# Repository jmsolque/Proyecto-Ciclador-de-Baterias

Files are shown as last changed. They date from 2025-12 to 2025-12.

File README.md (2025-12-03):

# Proyecto-Ciclador-de-Baterias
Este repositorio contiene los archivos correspondientes a un ciclador de módulos de baterías.

## Documentación

### Componentes Utilizados
<div align="center">

| Componente | Cantidad | Modelo | Utilización |
|:---:|:---:|:---:|:---:|
| Fuente de tensión | 1 | x | Alimentar algunos de los componentes utilizados. |
| Conversor DC/DC | 1 | TBA 1E | Tener tanto tensión positiva como negativa. |
| Varistor | 1 | x | Circuito de protección. |
| Resistencia 100 KΩ | 1 | x | Circuito de protección. |
| Diodo Zener | 1 | 1N4747 | Circuito de protección. |
| Transistor MOSFET | 1 | IRF9540N | Circuito de protección. |
| Transistor NPN | 2 | TIP120 | Uno para carga y otro para descarga. |
| Disipador Térmico | 2 | x | Disipar el calor de los transistores. |
| Inductor 10µH | 2 | x | Dos, para regular corriente de carga y descarga y poder utilizar el sistema de control. |
| Amplificador Operacional | 1 | LM353 | Controlar si funciona el circuito de carga o de descarga. |
| Sensores de Corriente | 2 | x | Para medir las corrientes de carga y descarga. |
| Delfino | 1 | C2000 | Controlador. |
| Medidor de Tensión | 1 | x | Incorporado en el C2000, para medir la tensión de la batería. |
| Convertidor Digital Analógico | 1 | x | Controlar si descarga o carga. |

</div>

### Ecuaciones utilizadas

La ecuación utilizada para el circuito de carga es:

$$
0 = -V_{carga} + L\frac{di_c}{dt} + V_{batería} 
$$

De donde se tiene que:

$$
V_{carga} = V_{cc} + V_{cp} 
$$

Con base en lo anterior, se considera que: 

$$ 
V_{cp} = V_{\text{batería}} 
$$

Esta igualdad se logra mediante un sistema de prealimentación que compensa la caída de tensión en los elementos intermedios y asegura que el valor aplicado en el punto de control coincida con el voltaje real de la batería.

Por lo cual se tiene que:

$$
\frac{di_c}{dt} = \frac{V_{cc}}{L}
$$

Y de esta forma la función de transferencia será:

$$
\frac{i_c(s)}{V_{cc}(s)} = \frac{1}{Ls}
$$

De forma similar se tendrá para el el circuito de descarga, para el cual lo de realizar los cálculos pertinentes se tendría que la función de transferencia sería.

$$
\frac{i_c(s)}{V_{dc}(s)} = -\frac{1}{Ls}
$$

Donde Vdc es la tensión de descarga.

## [PLECS](PLECS/)

En esta sección se encuentra el código utilizado para la implementación en PLECS y así poder utilizar un C2000, en esta misma también se muestran las simualciones.

## [PCB](PCB/)

En esta sección se encuentran los archivos utilizados para la creación de la PCB.

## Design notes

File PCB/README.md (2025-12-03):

# PCB

En esta sección se encuentran los archivos para la impresión de la PCB, junto con imágenes de referencia.

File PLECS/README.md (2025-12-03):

# PLECS

En esta sección se tiene la implementación en PLECS y a su vez las imágenes de las simulaciones obtenidas del mismo, como lo son su sistema de control y los circuitos de carga y descarga.

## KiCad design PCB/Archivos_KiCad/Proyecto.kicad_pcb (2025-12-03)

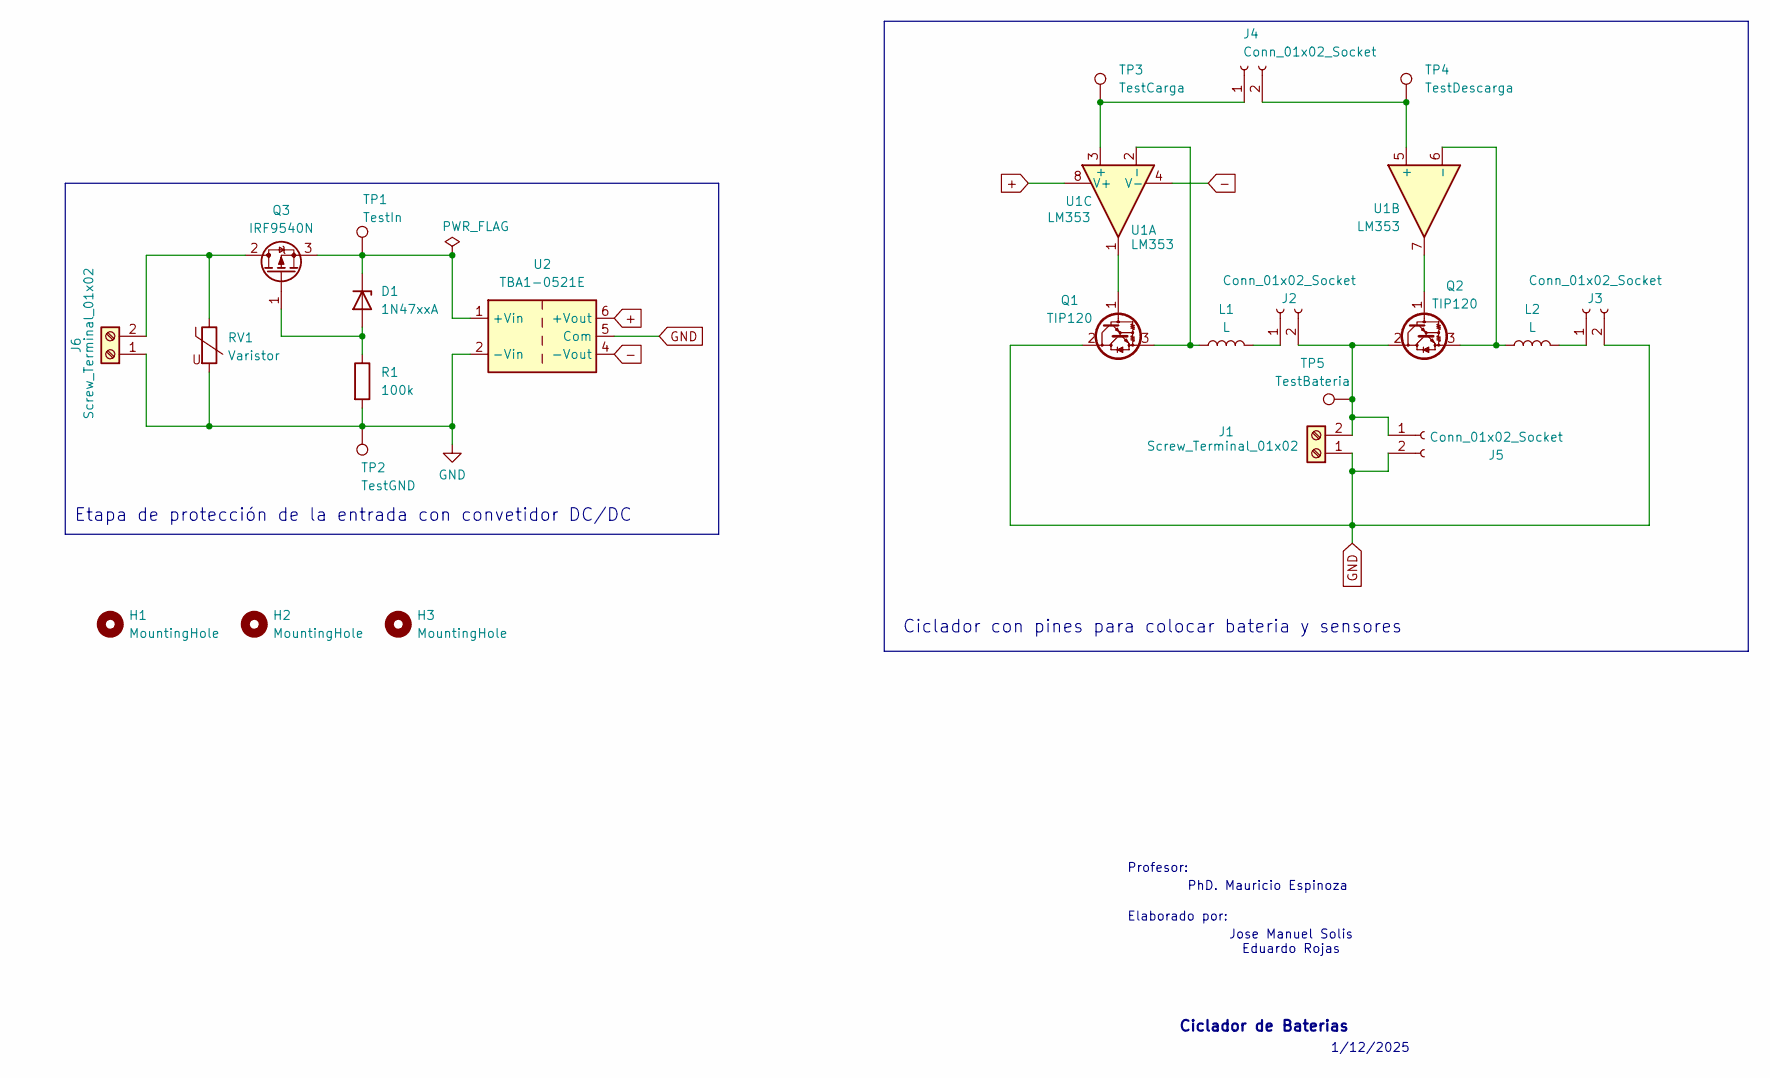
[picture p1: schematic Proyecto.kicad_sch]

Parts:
D1: 1N47xxA; D_DO-41_SOD81_P10.16mm_Horizontal
H1, H2, H3: MountingHole; MountingHole_2.2mm_M2
J1, J6: Screw_Terminal_01x02; TerminalBlock_Phoenix_MKDS-1,5-2_1x02_P5.00mm_Horizontal
J2, J3, J4, J5: Conn_01x02_Socket; PinSocket_1x02_P2.00mm_Vertical
L1, L2: L; L_Axial_L5.3mm_D2.2mm_P7.62mm_Horizontal_Vishay_IM-1
Q1, Q2: TIP120; TO-220-3_Vertical
Q3: IRF9540N; TO-220-3_Vertical
R1: 100k; R_Axial_DIN0207_L6.3mm_D2.5mm_P7.62mm_Horizontal
RV1: Varistor; RV_Disc_D7mm_W4mm_P5mm
TP1: TestIn; TestPoint_Loop_D2.54mm_Drill1.5mm_Beaded
TP2: TestGND; TestPoint_Loop_D2.54mm_Drill1.5mm_Beaded
TP3: TestCarga; TestPoint_Loop_D2.54mm_Drill1.5mm_Beaded
TP4: TestDescarga; TestPoint_Loop_D2.54mm_Drill1.5mm_Beaded
TP5: TestBateria; TestPoint_Loop_D2.54mm_Drill1.5mm_Beaded
U1: LM353; DIP-8_W7.62mm
U2: TBA1-0521E; Converter_DCDC_TRACO_TBA1-xxxxE_Dual_THT

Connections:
+: U1.8 (V+), U2.6 (+Vout)
-: U1.4 (V-), U2.4 (-Vout)
GND: J1.1, J3.2, J5.2, J6.1, Q1.2 (C), R1.2, RV1.2, TP2.1, U2.2 (-Vin), U2.5 (Com); also elsewhere on the board
unnamed: D1.2 (A), Q3.1 (G), R1.1
unnamed: D1.1 (K), Q3.3 (S), TP1.1, U2.1 (+Vin)
unnamed 5: J1.2, J2.2, J5.1, Q2.2 (C), TP5.1; also elsewhere on the board
unnamed: J2.1, L1.2
unnamed: J3.1, L2.2
unnamed: J4.1, TP3.1, U1.3 (+)
unnamed: J4.2, TP4.1, U1.5 (+)
unnamed 10: J6.2, Q3.2 (D), RV1.1; also elsewhere on the board
unnamed: Q1.1 (B), U1.1
unnamed: L1.1, Q1.3 (E), U1.2 (-)
unnamed: Q2.1 (B), U1.7
unnamed: L2.1, Q2.3 (E), U1.6 (-)

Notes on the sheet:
Jose Manuel Solis Eduardo Rojas
1/12/2025
Elaborado por:
Profesor:
Ciclador con pines para colocar bateria y sensores
Ciclador de Baterias
Etapa de protección de la entrada con convetidor DC/DC
PhD. Mauricio Espinoza

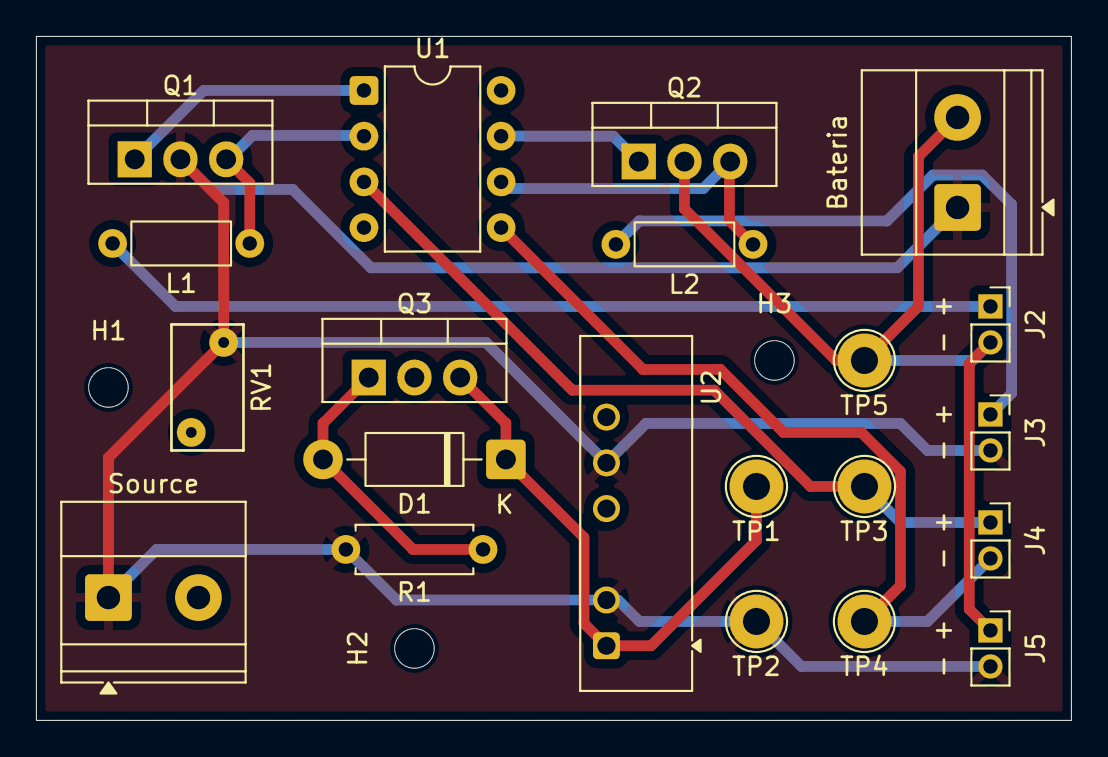
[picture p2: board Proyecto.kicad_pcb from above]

Board: 4 copper layers, 57.5 x 38.0 mm, 24 parts (0 on the bottom side), 15 nets.

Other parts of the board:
Bateria: Screw_Terminal_01x02; TerminalBlock_Phoenix_MKDS-1,5-2_1x02_P5.00mm_Horizontal
Source: Screw_Terminal_01x02; TerminalBlock_Phoenix_MKDS-1,5-2_1x02_P5.00mm_Horizontal

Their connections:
GND: Bateria.1, Source.1; also elsewhere on the board
unnamed 5: Bateria.2; also elsewhere on the board
unnamed 10: Source.2; also elsewhere on the board
